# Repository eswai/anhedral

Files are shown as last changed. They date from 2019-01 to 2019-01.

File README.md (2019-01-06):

# 自作キーボード　ANHEDRAL rev. 1

## 特徴
- 一体型、非分割キーボード
- 完全左右対称、row staggeredなSemiErgoキーレイアウト https://github.com/mtei/SemiErgo_Layout
- 親指シフト対応
  - 親指で押すキーが多いので、専用の親指シフトキーを配置可能
  - QMKでの親指シフト入力が可能(補助ソフトのインストールが不要)
  - modifier行を0.25U下げることで同時押しを容易に
  - https://github.com/eswai/qmk_firmware/tree/master/keyboards/crkbd/keymaps/nicola
- Cherry MXまたは互換キースイッチ専用、ホットスワップ対応
- 104キーキャップ対応

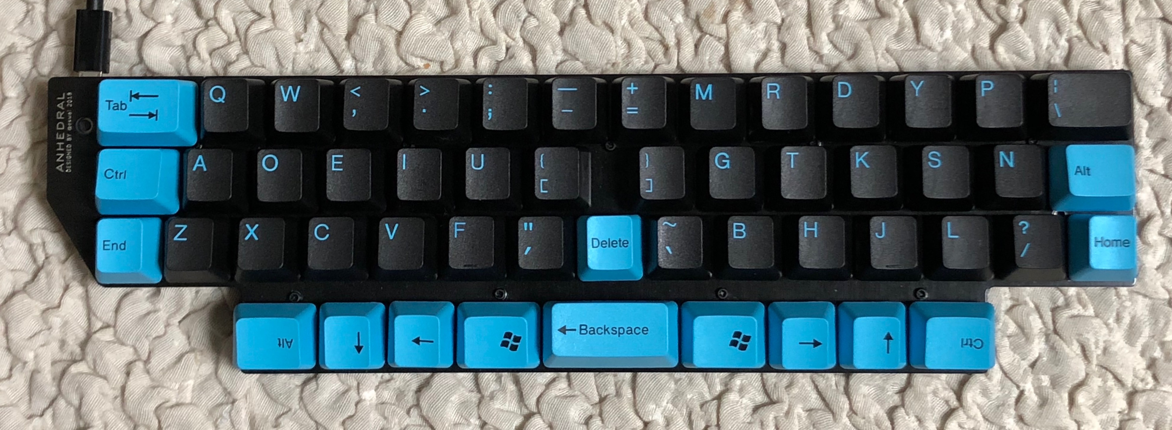
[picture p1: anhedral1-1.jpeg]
ANHEDRAL


## キーマップの例

eucalyn配列、親指のシフトキーを親指シフトのための親指キーとして使う。
```
//+-------+-------+-------+-------+-------+-------+-------+       +-------+-------+-------+-------+-------+-------+-------+
    KC_TAB,   KC_Q,   KC_W,KC_COMM, KC_DOT,KC_SCLN,KC_MINS,         KC_EQL,   KC_M,   KC_R,   KC_D,   KC_Y,   KC_P,KC_BSLS, \
//+-------+-------+-------+-------+-------+-------+-------+       +-------+-------+-------+-------+-------+-------+-------+
   KC_LCTL,   KC_A,   KC_O,   KC_E,   KC_I,   KC_U,KC_LBRC,        KC_RBRC,   KC_G,   KC_T,   KC_K,   KC_S,   KC_N,KC_RCMD, \
//+-------+-------+-------+-------+-------+-------+-------+-------+-------+-------+-------+-------+-------+-------+-------+
   SFT_ESC,   KC_Z,   KC_X,   KC_C,   KC_V,   KC_F, KC_GRV,KC_BSPC,KC_QUOT,   KC_B,   KC_H,   KC_J,   KC_L,KC_SLSH,KC_RALT, \
//+-------+-------+-------+-------+-------+-------+-------+-------+-------+-------+-------+-------+-------+-------+-------+
                              EISU,  LOWER, KC_SPC,KC_LSFT, KC_DEL,KC_RSFT, KC_ENT,  RAISE,   KANA \
//                        +-------+-------+-------+-------+-------+-------+-------+-------+-------+
```

## BOM 部品リスト
- トッププレート(PCB 1.6mm) 1個
- ボトムプレート(PCB 1.6mm) 1個
- ミドルプレート(PCB 1.6mm) 1個
- ねじ M2 x 4mm 22個
- スペーサ M2 x 7mm 11個
- Pro Micro 1個
- キースイッチ 52個
- ANSI104 キーキャップ 
- 2Uスタビライザー (PCBマウント) 1個
- 表面実装用タクトスイッチ TSHA-T-2.5B2-19E 1個
- ダイオード1N4148(スルーホールまたは表面実装) 52個
- PCBソケット　52個
- ゴム足大 3,4個 
- ゴム足小 3,4個

## ファームウェア
- 公開予定

## 既知の不具合
- ボトムプレートに固定用の穴が一つ足りない
- リセット用のタクトスイッチがトッププレートと干渉するため予定していたスルーホールのスイッチではなく、高さの低い表面実装のタクトスイッチへ変更
- トッププレートが小さく、modifier行の左右の端の1.5Uのキーが少しはみ出す

## 改善したい点
- Pro Microが下側で露出するのは危険なので、ボトムプレートでカバーしたい
- ノートPCの前に置くとケーブルが邪魔なので、横向きにだす
- 親指で押すキーの配置を見直す

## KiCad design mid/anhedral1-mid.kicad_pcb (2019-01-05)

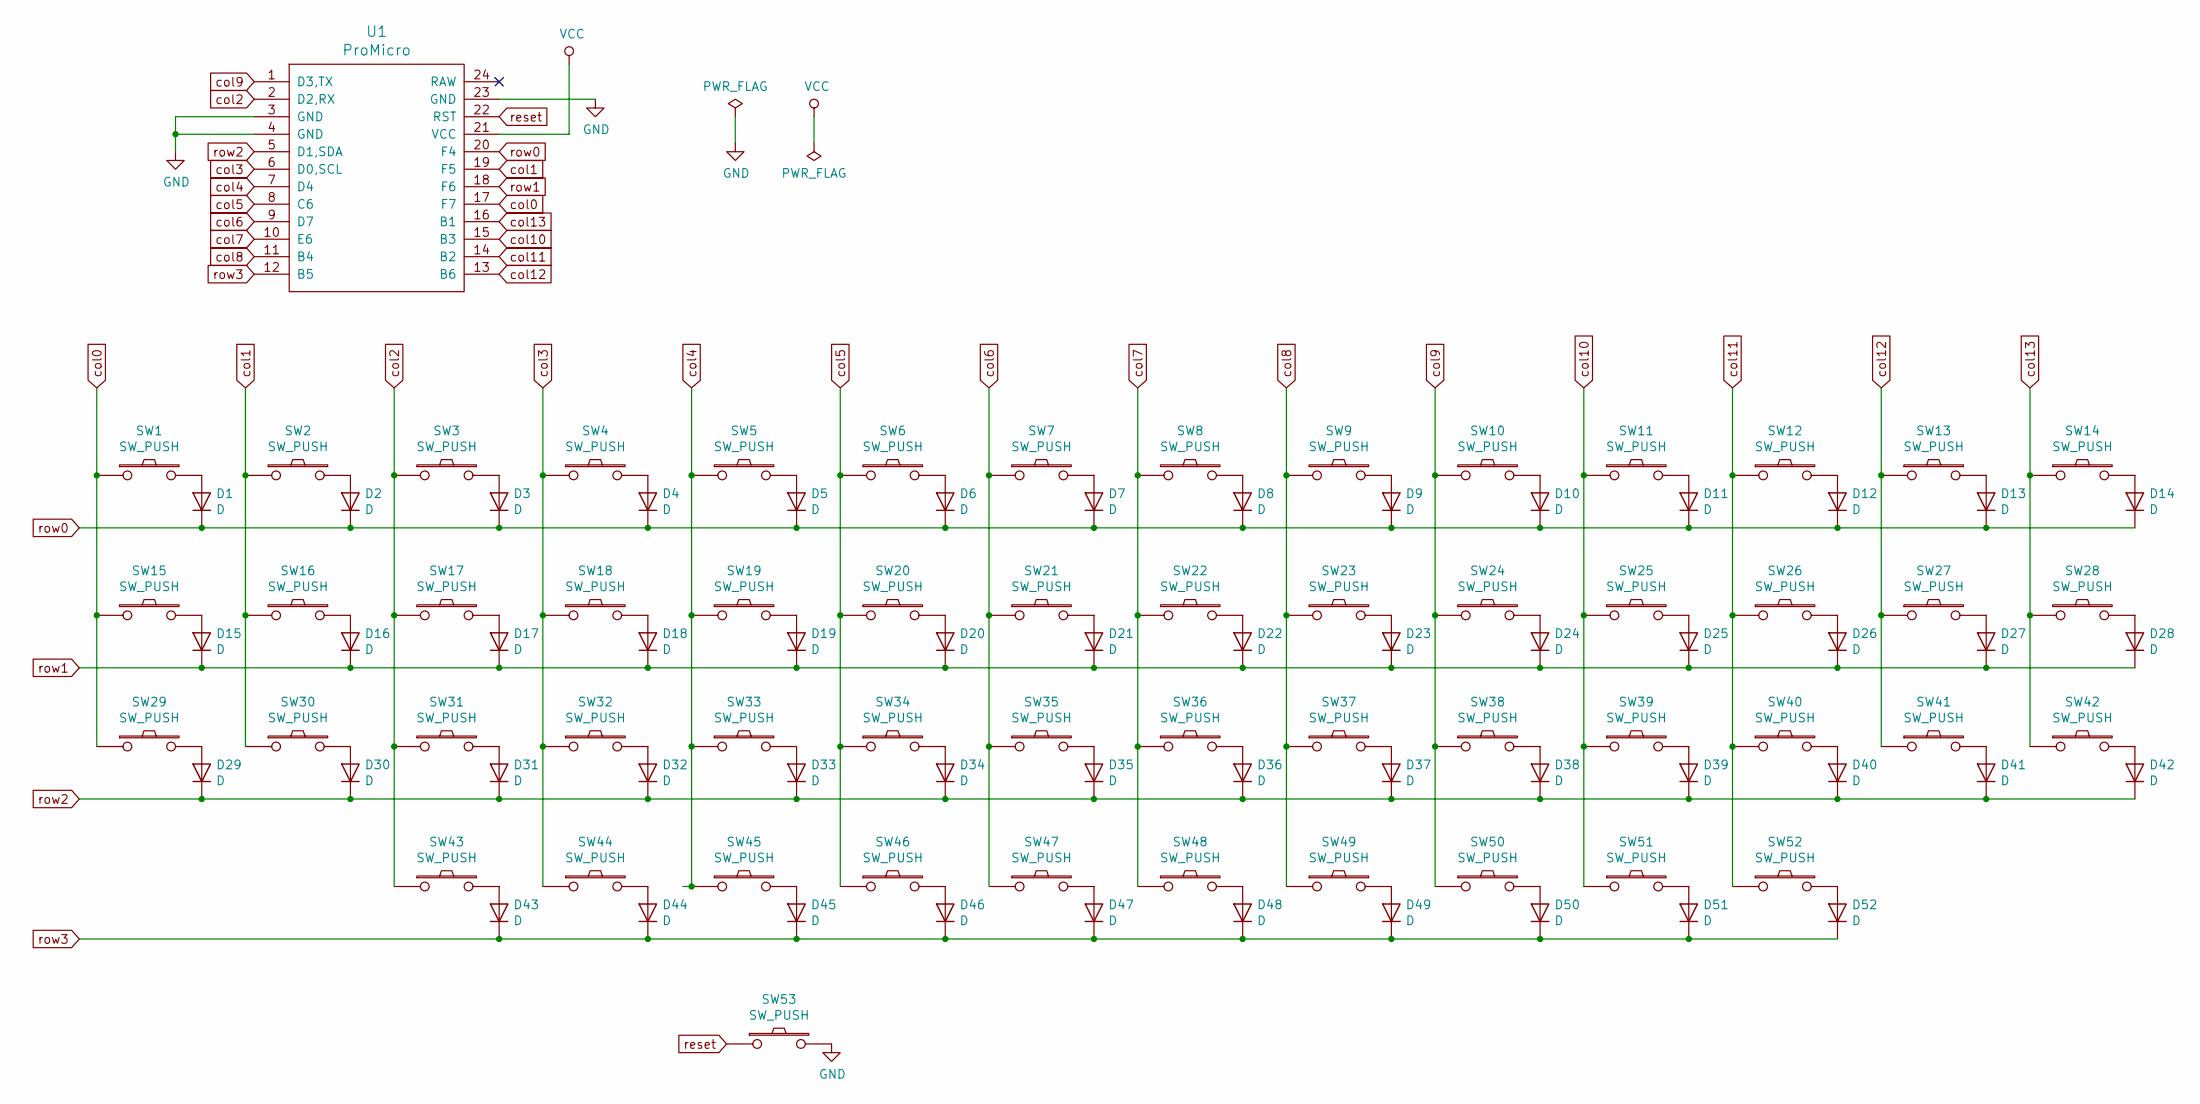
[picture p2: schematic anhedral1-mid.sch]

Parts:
D1, D2, D3, D4, D5, D6, D7, D8, D9, D10, D11, D12, D13, D14, D15, D16, D17, D18, D19, D20, D21, D22, D23, D24, D25, D26, D27, D28, D29, D30, D31, D32, D33, D34, D35, D36, D37, D38, D39, D40, D41, D42, D43, D44, D45, D46, D47, D48, D49, D50, D51, D52: D; Diode-dual
SW1, SW2, SW3, SW4, SW5, SW6, SW7, SW8, SW9, SW10, SW11, SW12, SW13, SW14, SW15, SW16, SW17, SW18, SW19, SW20, SW21, SW22, SW23, SW24, SW25, SW26, SW27, SW28, SW29, SW30, SW31, SW32, SW33, SW34, SW35, SW36, SW37, SW38, SW39, SW40, SW41, SW42, SW43, SW44, SW45, SW46, SW48, SW49, SW50, SW51, SW52: SW_PUSH; CherryMX_Hotswap
SW47: SW_PUSH; CherryMX_Hotswap_2u
SW53: SW_PUSH; ResetSW_4P
U1: ProMicro; ArduinoProMicro

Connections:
GND: SW53.2, U1.3 (GND), U1.4 (GND), U1.23 (GND)
unnamed: D1.2 (A), SW1.2
unnamed: D2.2 (A), SW2.2
unnamed: D3.2 (A), SW3.2
unnamed: D4.2 (A), SW4.2
unnamed: D5.2 (A), SW5.2
unnamed: D6.2 (A), SW6.2
unnamed: D7.2 (A), SW7.2
unnamed: D8.2 (A), SW8.2
unnamed: D9.2 (A), SW9.2
unnamed: D10.2 (A), SW10.2
unnamed: D11.2 (A), SW11.2
unnamed: D12.2 (A), SW12.2
unnamed: D13.2 (A), SW13.2
unnamed: D14.2 (A), SW14.2
unnamed: D15.2 (A), SW15.2
unnamed: D16.2 (A), SW16.2
unnamed: D17.2 (A), SW17.2
unnamed: D18.2 (A), SW18.2
unnamed: D19.2 (A), SW19.2
unnamed: D20.2 (A), SW20.2
unnamed: D21.2 (A), SW21.2
unnamed: D22.2 (A), SW22.2
unnamed: D23.2 (A), SW23.2
unnamed: D24.2 (A), SW24.2
unnamed: D25.2 (A), SW25.2
unnamed: D26.2 (A), SW26.2
unnamed: D27.2 (A), SW27.2
unnamed: D28.2 (A), SW28.2
unnamed: D29.2 (A), SW29.2
unnamed: D30.2 (A), SW30.2
unnamed: D31.2 (A), SW31.2
unnamed: D32.2 (A), SW32.2
unnamed: D33.2 (A), SW33.2
unnamed: D34.2 (A), SW34.2
unnamed: D35.2 (A), SW35.2
unnamed: D36.2 (A), SW36.2
unnamed: D37.2 (A), SW37.2
unnamed: D38.2 (A), SW38.2
unnamed: D39.2 (A), SW39.2
unnamed: D40.2 (A), SW40.2
unnamed: D41.2 (A), SW41.2
unnamed: D42.2 (A), SW42.2
unnamed: D43.2 (A), SW43.2
unnamed: D44.2 (A), SW44.2
unnamed: D45.2 (A), SW45.2
unnamed: D46.2 (A), SW46.2
unnamed: D47.2 (A), SW47.2
unnamed: D48.2 (A), SW48.2
unnamed: D49.2 (A), SW49.2
unnamed: D50.2 (A), SW50.2
unnamed: D51.2 (A), SW51.2
unnamed: D52.2 (A), SW52.2
VCC: U1.21 (VCC)
col0: SW1.1, SW15.1, SW29.1, U1.17 (F7)
col1: SW2.1, SW16.1, SW30.1, U1.19 (F5)
col2: SW3.1, SW17.1, SW31.1, SW43.1, U1.2 (D2,RX)
col3: SW4.1, SW18.1, SW32.1, SW44.1, U1.6 (D0,SCL)
col4: SW5.1, SW19.1, SW33.1, SW45.1, U1.7 (D4)
col5: SW6.1, SW20.1, SW34.1, SW46.1, U1.8 (C6)
col6: SW7.1, SW21.1, SW35.1, SW47.1, U1.9 (D7)
col7: SW8.1, SW22.1, SW36.1, SW48.1, U1.10 (E6)
col8: SW9.1, SW23.1, SW37.1, SW49.1, U1.11 (B4)
col9: SW10.1, SW24.1, SW38.1, SW50.1, U1.1 (D3,TX)
col10: SW11.1, SW25.1, SW39.1, SW51.1, U1.15 (B3)
col11: SW12.1, SW26.1, SW40.1, SW52.1, U1.14 (B2)
col12: SW13.1, SW27.1, SW41.1, U1.13 (B6)
col13: SW14.1, SW28.1, SW42.1, U1.16 (B1)
reset: SW53.1, U1.22 (RST)
row0: D1.1 (K), D2.1 (K), D3.1 (K), D4.1 (K), D5.1 (K), D6.1 (K), D7.1 (K), D8.1 (K), D9.1 (K), D10.1 (K), D11.1 (K), D12.1 (K), D13.1 (K), D14.1 (K), U1.20 (F4)
row1: D15.1 (K), D16.1 (K), D17.1 (K), D18.1 (K), D19.1 (K), D20.1 (K), D21.1 (K), D22.1 (K), D23.1 (K), D24.1 (K), D25.1 (K), D26.1 (K), D27.1 (K), D28.1 (K), U1.18 (F6)
row2: D29.1 (K), D30.1 (K), D31.1 (K), D32.1 (K), D33.1 (K), D34.1 (K), D35.1 (K), D36.1 (K), D37.1 (K), D38.1 (K), D39.1 (K), D40.1 (K), D41.1 (K), D42.1 (K), U1.5 (D1,SDA)
row3: D43.1 (K), D44.1 (K), D45.1 (K), D46.1 (K), D47.1 (K), D48.1 (K), D49.1 (K), D50.1 (K), D51.1 (K), D52.1 (K), U1.12 (B5)

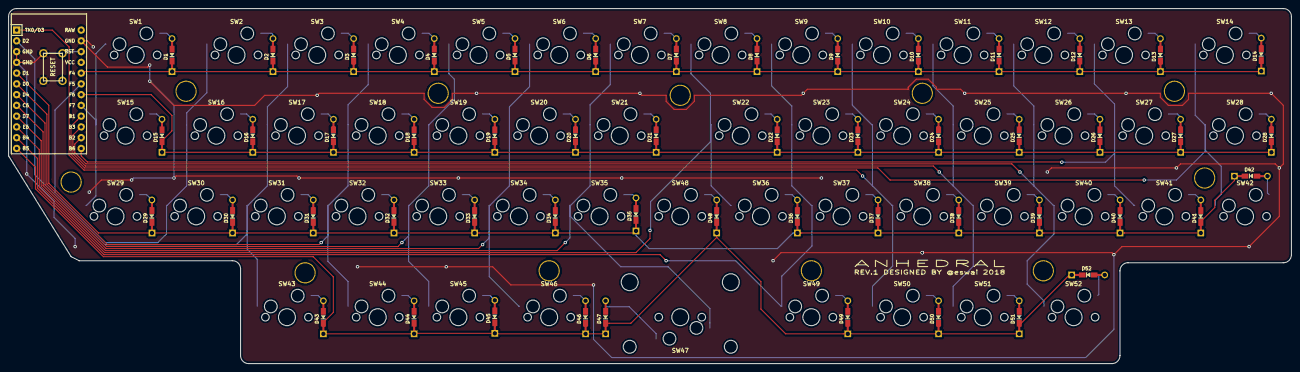
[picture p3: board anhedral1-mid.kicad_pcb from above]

Board: 2 copper layers, 302.9 x 83.8 mm, 117 parts (0 on the bottom side), 72 nets.

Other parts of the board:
Ref**: Val**; HOLE
Ref**#2, Ref**#3, Ref**#4, Ref**#5, Ref**#6, Ref**#7, Ref**#8, Ref**#9, Ref**#10, Ref**#11: Val**; HOLE
